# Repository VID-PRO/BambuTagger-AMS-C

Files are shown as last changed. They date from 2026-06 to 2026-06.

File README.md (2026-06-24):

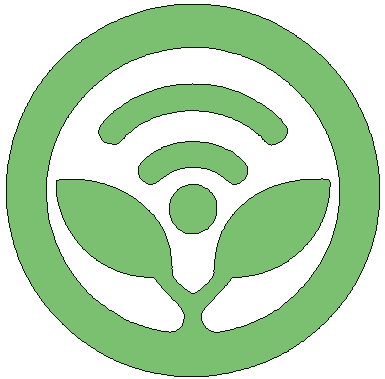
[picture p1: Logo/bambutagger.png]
#  BambuTagger-AMS-C

Multi-spool NFC tag reader for Bambu Lab printers. Reads 4 Bambu Lab filament spool tags via RC522, displays live printer AMS tray data over MQTT, and sends RFID tag data to the printer/BMCU. Fully configurable via web interface with automatic AP fallback and OTA firmware updates.



<p align="center">
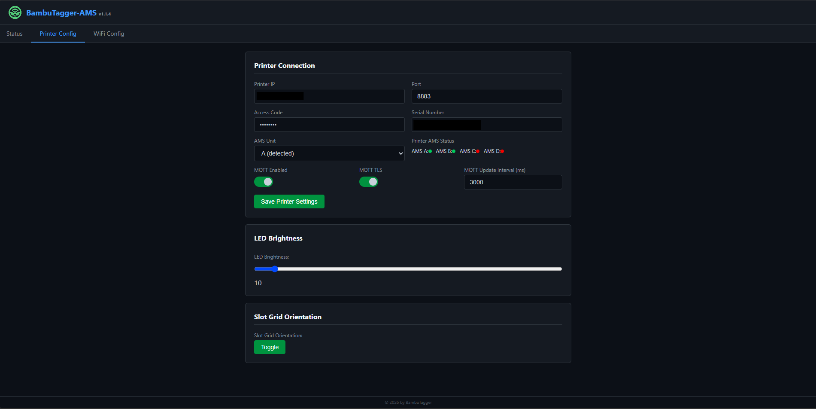
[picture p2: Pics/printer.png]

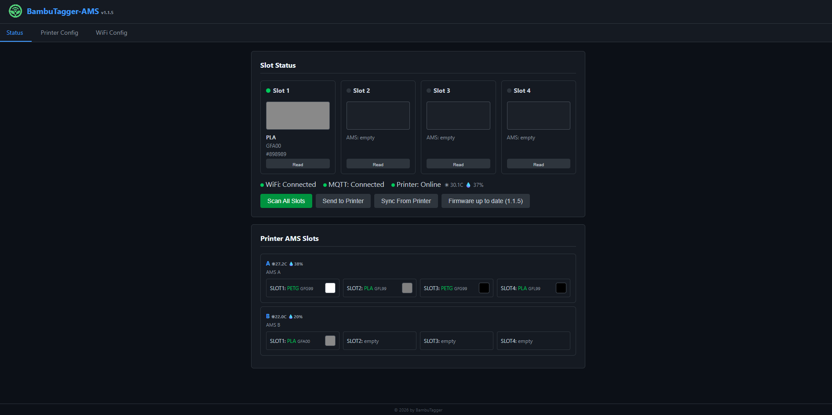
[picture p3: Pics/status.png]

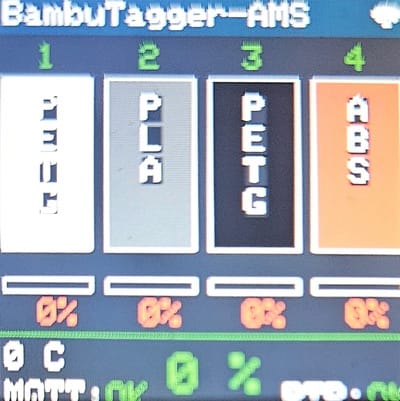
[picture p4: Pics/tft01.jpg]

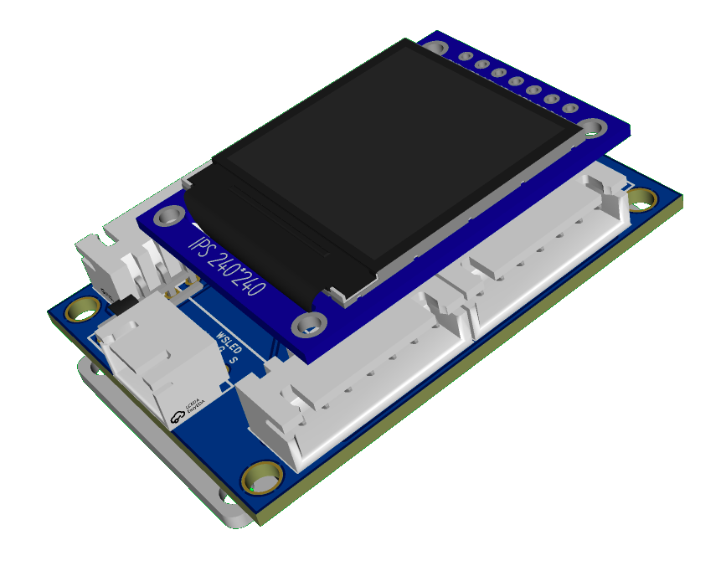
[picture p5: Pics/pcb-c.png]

</p>

---

## Features

| Category | Details |
|---|---|
| **RFID** | 4x RC522 on shared SPI bus; MIFARE Classic 1K (Bambu Lab) + NTAG (SpoolEase/TigerTag/OpenTag3D/OpenSpool) auto-detection |
| **Key derivation** | HKDF-SHA256 with Bambu Lab salt — no hardcoded keys |
| **Tag parsers** | TigerTag v2.1 binary, OpenTag3D MIME binary, OpenSpool JSON, SpoolEase NDEF URI, nested NDEF recursion |
| **Live AMS sync** | Reads tray data (material, color, type) from printer over MQTT |
| **BMCU support** | Sends `ams_filament_setting` with correct `tray_type`, `tray_color`, `nozzle_temp_min/max` |
| **TFT display** | 240×240 1.3" ST7789VW with boot splash, live AMS tray data, OTA progress, BME280 temp/humidity |
| **LEDs** | 4x WS2812 addressable LEDs with per-slot color from printer AMS tray data |
| **Web UI** | 3-tab SPA: Status (merged slots + color swatches), Printer Config, WiFi Config |
| **MQTT bridge** | Subscribes to printer status, publishes `ams_filament_setting` commands |
| **WiFi** | Auto-STA on boot; AP fallback `192.168.4.1` with captive portal |
| **OTA updates** | One-click firmware update from GitHub Releases with TFT progress bar |
| **CI/CD** | GitHub Actions: build on commit, release on version tags |

---

## Hardware

### Bill of Materials

| Component | Notes | Buy |
|---|---|-----
| **ESP32** Dev Module | Base board | https://de.aliexpress.com/item/1005006589341221.html |
| **4x RC522** RFID/NFC readers | SPI interface, shared bus | https://de.aliexpress.com/item/1005006233005745.html |
| **4x WS2812** addressable LEDs | Daisy-chained, single data pin | https://de.aliexpress.com/item/32560280169.html |
| **240×240 1.3" TFT** | ST7789VW SPI display | https://www.aliexpress.com/item/1005007094147766.html |
| **BME280** sensor | Temperature/humidity, I2C | https://de.aliexpress.com/item/1005006824236173.html |
| **PCB** | DIY PCB from JLPCB<br/>only > v1.2 | https://oshwlab.com/bambutagger/project_hdkkdlsn |

### Pin Assignments

**SPI Bus (shared by all RC522 readers)**

| Signal | GPIO |
|---|---|
| MOSI | 23 |
| MISO | 19 |
| SCK | 18 |

**RC522 Readers**

| Reader | SS Pin | RST Pin | Slot | WS2812 Pixel |
|---|---|---|---|---|
| #1 | 13 | 26 | 1 | 0 |
| #2 | 12 | 25 | 2 | 1 |
| #3 | 14 | 33 | 3 | 2 |
| #4 | 27 | 32 | 4 | 3 |

**TFT Display (ST7789VW SPI)**

| Signal | GPIO |
|---|---|
| SDA (MOSI) | 17 |
| SCL (SCK) | 16 |
| DC | 4 |
| RES | 5 |
| BLK (Backlight) | 2 |

**WS2812 LEDs**

| Signal | GPIO |
|---|---|
| Data | 15 |

**BME280**

| Signal | GPIO |
|---|---|
| SCL | 21 |
| SDA | 22 |

---

## Software

### Required Libraries (Arduino Library Manager)

| Library | Version | Notes |
|---|---|---|
| `MFRC522-spi-i2c-uart-async` | latest | Multi-reader SPI sharing (not standard MFRC522) |
| `Adafruit NeoPixel` | ≥ 1.12 | WS2812 LED control |
| `Adafruit GFX Library` | ≥ 1.11 | Graphics primitives |
| `Adafruit ST7735 and ST7789 Library` | ≥ 1.10 | TFT display driver |
| `PubSubClient` | ≥ 2.8 | MQTT client |
| `ArduinoJson` | ≥ 6.x or 7.x | JSON parsing |
| `Adafruit BME280 Library` | latest | Temperature/humidity sensor |
| `mbedTLS` | Built-in | HKDF-SHA256 key derivation |

### Board Settings (Arduino IDE)

| Setting | Value |
|---|---|
| Board | **ESP32 Dev Module** |
| Flash Size | **4 MB** |
| Partition Scheme | **Default 4MB with spiffs** |
| Upload Speed | 921600 |
| Monitor Speed | **115200** |

### Building

1. Install **ESP32 board package** (≥ 3.x):  
   File → Preferences → Additional Board Manager URLs:  
   `https://espressif.github.io/arduino-esp32/package_esp32_index.json`
2. Install libraries listed above via **Tools → Manage Libraries**.
3. Open `BambuTagger-AMS-C.ino`, select **ESP32 Dev Module**, and upload.

---

## WiFi & AP Mode

| Scenario | Behavior |
|---|---|
| No WiFi configured | Opens AP immediately |
| WiFi connection fails | Opens AP after 15 seconds |
| AP active, credentials exist | Retries STA connection every 30 seconds |
| STA connects while AP active | Closes AP, switches to normal mode |

**AP Details:**
- **SSID**: Device name (default: `BambuTagger-AMS`)
- **Security**: Open (no password)
- **IP**: `192.168.4.1`
- **Captive portal**: DNS redirects all domains to the config page

---

## Web Interface

Open a browser to the ESP32's IP (shown on TFT), or `http://192.168.4.1` in AP mode.

| Tab | Description |
|-----|---|
| **Status** | Merged slot status with AMS data + scanned tag data, color swatches, printer AMS cards, OTA button |
| **Printer Config** | Printer IP, Port (8883), Access Code, Serial Number, AMS Unit selector (A/B/C/D), MQTT settings |
| **WiFi Config** | SSID, Password, Device Name |

---

## TFT Display (240×240 1.3" ST7789VW)

```
┌────────────────────────────────────────┐
│ Device Name                      WiFi  │  ← status bar (white bg)
├────────────────────────────────────────┤
│ 1: PLA          [■] #C0C0C0FF   100%   │  ← color swatch + percentage
│ 2: empty                               │
│ 3: empty                               │
│ 4: empty                               │
├────────────────────────────────────────┤
│ 22C        45%                         │  ← BME280 (orange/blue)
│ MQTT:OK                         PTR:OK │  ← status line
└────────────────────────────────────────┘
```

OTA progress shown on TFT with header/footer preserved:  
"OTA Update" → "Downloading..." → "Flashing... 45%" → auto-reboot

---

## Printer Communication

### Subscribe

- **Topic**: `device/<serial>/report`
- **Data**: `push_status` (periodic, ~3KB), `get_version` responses

### Publish

- **Topic**: `device/<serial>/request`

**`ams_filament_setting`** structure:

```json
{
  "print": {
    "sequence_id": "0",
    "command": "ams_filament_setting",
    "ams_id": 0,
    "tray_id": 0,
    "tray_info_idx": "GFA00",
    "tray_color": "RRGGBBFF",
    "nozzle_temp_min": 190,
    "nozzle_temp_max": 230,
    "tray_type": "PLA"
  }
}
```

- `tray_type` derived from filament index prefix (GFA→PLA, GFG→PETG, etc.)
- `tray_color` forced to RRGGBBFF format
- `nozzle_temp_min/max` from tag block 6

---

## Tag Format & Reading

### Supported Tag Types

| Tag Type | Format | Example |
|---|---|---|
| **Bambu Lab** | MIFARE Classic 1K | `Bambu - PLA · C12E1FFF · 1000g/1000g` |
| **SpoolEase** | NTAG, NDEF URI | `SpoolEase - PLA · 000000FF · 1000g/1036g` |
| **TigerTag** | NTAG, binary v2.1 | `TigerTag - ASA-AF · F078B4FF · 1000g/1000g` |
| **OpenSpool** | NTAG, NDEF JSON | `OpenSpool - ASA-AF · F078B4FF · 1000g/1000g` |
| **OpenTag3D** | NTAG, MIME binary | `OpenTag3D - ASA-AF · F078B4FF · 1000g/1000g` |

### Bambu Lab (MIFARE Classic 1K)

| Block | Content |
|---|---|
| 0 | UID (4 bytes) |
| 1 | Variant ID + Material index (e.g. "GFA00") |
| 2 | Filament type short name |
| 4 | Detailed type string (e.g. "PLA Basic") |
| 5 | RGBA color (bytes 0-3) + spool weight LE (bytes 4-5) |
| 6 | Nozzle temps (bytes 8-11 LE) |

### SpoolEase (NTAG, NDEF URI)

URL format: `https://tag.spoolease.io/S1/?TG=...&M=PLA&CC=000000FF&SC=GFL99&WL=1000&WE=179&WF=1215&NN=190&NX=240`

| Param | Field | Description |
|---|---|---|
| `M=` | display type | e.g. "PLA", "PETG" |
| `SC=` | `materialType` | Bambu index for MQTT (e.g. "GFL99") |
| `CC=` | `colorHex` | RGBA hex (e.g. "000000FF") |
| `B=` | `manufacturer` | Brand name (e.g. "Jayo") |
| `WL=` | `remainingGrams` | Remaining filament weight |
| `WE=` | empty spool | Empty spool weight |
| `WF=` | full spool | `totalGrams = WF - WE` |
| `NN=` | `nozzleTempMin` | Min nozzle temp °C |
| `NX=` | `nozzleTempMax` | Max nozzle temp °C |

### TigerTag (NTAG, binary v2.1)

| Offset | Size | Field |
|---|---|---|
| +0 | 4 | ID TigerTag magic (0x5BF59264/0xBC0FCB97/0x6C41A2E1) |
| +4 | 4 | Product ID |
| +8 | 2 | Material ID → lookup table (PLA/PETG/ABS/TPU...) |
| +14 | 2 | Brand ID |
| +16 | 4 | Color 1 RGBA |
| +20 | 3 | Measure (u24 BE) |
| +24 | 2 | Nozzle Temp Min |
| +26 | 2 | Nozzle Temp Max |
| +76 | 3 | Measure Available |

Known material IDs: PLA=38219, PETG=38256, ABS=20562, etc.

### Authentication & Reading

- **Tag auto-detect**: SAK-based type detection (MIFARE 1K vs NTAG)
- **HKDF-SHA256** derives 16 per-sector Key A/B from 4-byte UID
- Bambu KDF salt/info vectors from reverse-engineered firmware
- Falls back to default key `0xFF...FF` for blank sectors
- Failed auth re-wakes tag via antenna power-cycle
- Dead readers auto-skipped (version register 0x92/0x91/0xB2 check)
- SPI: 1 MHz via `MFRC522_SPI`
- NTAG: page-level reads (page+=4, 4 pages per MIFARE_Read)

### Filament Type Mapping

| Prefix | Type |
|---|---|
| GFA-GFE, GFL | PLA |
| GFG | PETG |
| GFH, GFI | ABS |
| GFJ | ASA |
| GFK | TPU |

---

## OTA Updates

- **Button**: "Update Firmware" on Status page (shows "Update to vX.Y.Z" or "up to date")
- **Overlay**: full-screen progress overlay with spinner, status text, progress bar
- **Endpoint**: `POST /api/ota` triggers update, `GET /api/ota-check` checks for newer version
- Downloads latest `.ino.bin` from GitHub Releases, flashes via `Update.h`
- 3 retry attempts with 5s stall detection, fresh HTTP client per attempt
- TFT shows "Checking version..." → "Downloading..." → "Flashing..." with percentage
- Device auto-reboots after successful flash, web UI auto-reloads

---

## CI / CD

Workflow at `GHActions/release.yml`:

- **On push/PR**: compiles sketch, uploads artifacts
- **On release tag**: creates merged flash binary + OTA binary, attaches to GitHub Release
- Arduino cache for fast rebuilds, pinned esp32:esp32@3.0.7 core

---

## Configuration Defaults

| Setting | Default |
|---|---|
| WiFi SSID | (empty) |
| WiFi Password | (empty) |
| Device Name | BambuTagger-AMS |
| Printer IP | 192.168.1.100 |
| Printer Port | 8883 |
| Access Code | (empty) |
| Printer Serial | (empty) |
| AMS Unit | A (0) |
| MQTT Enabled | Yes |
| MQTT TLS | No |
| MQTT Update Interval | 3000 ms |
| RFID Poll Interval | 100 ms |
| Firmware Version | 1.0.8 |

---

## Credits & References

- [RFID-Tag-Guide](https://github.com/Bambu-Research-Group/RFID-Tag-Guide)
- Display library: [Adafruit ST7735/ST7789](https://github.com/adafruit/Adafruit-ST7735-Library)
- RFID library: [MFRC522-spi-i2c-uart-async](https://github.com/miguelbalboa/rfid)
- OpenTag3D spec: [opentag3d.info](https://opentag3d.info)

---

## License

This project is provided as-is for personal and educational use.  
Bambu Lab trademarks and spool tag data formats are the property of Bambu Lab.

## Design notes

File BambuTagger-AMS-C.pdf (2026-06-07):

# BambuTagger-AMS-C

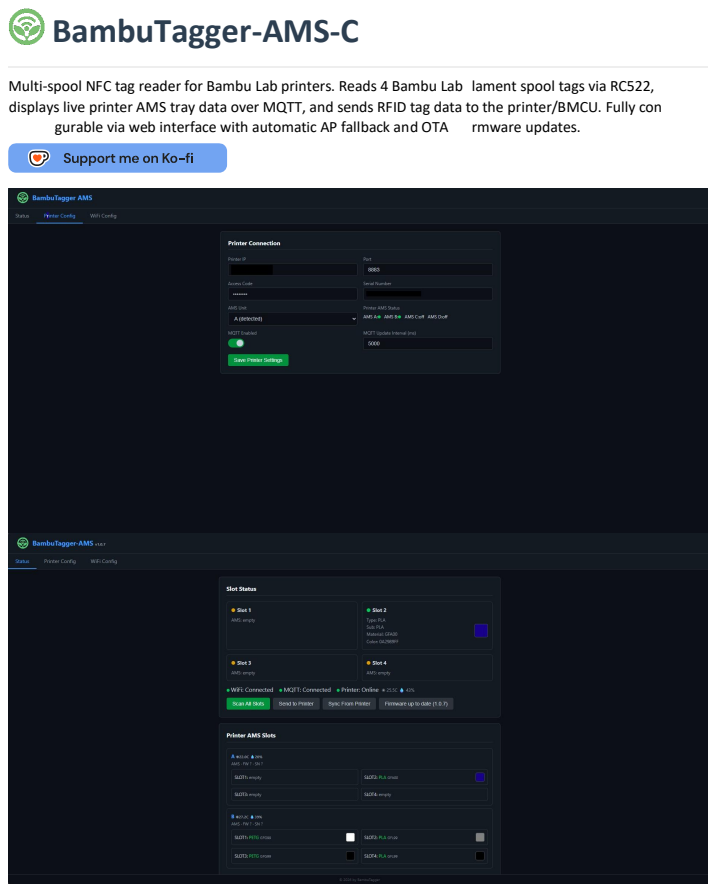
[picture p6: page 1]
gurable via web interface with automatic AP fallback and OTA; rmware updates.

Multi-spool NFC tag reader for Bambu Lab printers. Reads 4 Bambu Lab lament spool tags via RC522,
displays live printer AMS tray data over MQTT, and sends RFID tag data to the printer/BMCU. Fully con

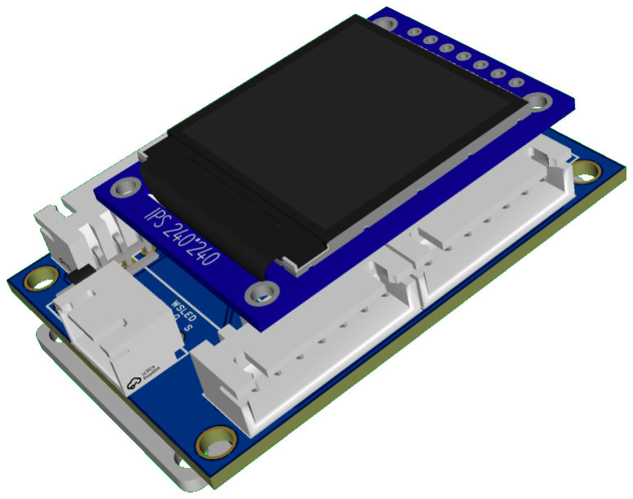
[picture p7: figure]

# Features

Category | Details
RFID | 4x RC522 on shared SPI bus; MIFARE Classic 1K (Bambu Lab) + NTAG (SpoolEase/TigerTag/OpenTag3D/OpenSpool) auto-detection
Key derivation | HKDF-SHA256 with Bambu Lab salt — no hardcoded keys
Tag parsers | TigerTag v2.1 binary, OpenTag3D MIME binary, OpenSpool JSON, SpoolEase NDEF URI, nested NDEF recursion
Live AMS sync | Reads tray data (material, color, type) from printer over MQTT
BMCU support | Sends ams_filament_setting with correct tray_type , tray_color , nozzle_temp_min/max
TFT display | 240×240 1.3" ST7789VW with boot splash, live AMS tray data, OTA progress, BME280 temp/humidity
Category | Details

LEDs | 4x WS2812 addressable LEDs with per-slot color from printer AMS tray data
Web UI | 3-tab SPA: Status (merged slots + color swatches), Printer Con g, WiFi Con g
MQTT bridge | Subscribes to printer status, publishes ams_filament_setting commands
WiFi | Auto-STA on boot; AP fallback 192.168.4.1 with captive portal
OTA updates | One-click rmware update from GitHub Releases with TFT progress bar
CI/CD | GitHub Actions: build on commit, release on version tags

# Hardware

## Bill of Materials

Component | Notes | Buy
ESP32 Dev Module | Base board | https://de.aliexpress.com/item/1005006589341221.html
4x RC522 RFID/NFC readers | SPI interface, shared bus | https://de.aliexpress.com/item/1005006233005745.html
4x WS2812 addressable LEDs | Daisy-chained, single data pin | https://de.aliexpress.com/item/32560280169.html
240×240 1.3" TFT | ST7789VW SPI display | https://www.aliexpress.com/item/1005007094147766.html
BME280 sensor | Temperature/humidity, I2C | https://de.aliexpress.com/item/1005006824236173.html
PCB | DIY PCB from JLPCB | https://oshwlab.com/bambutagger/project_hdkkdlsn

## Pin Assignments

SPI Bus (shared by all RC522 readers)

Signal | GPIO
MOSI | 23
Signal | GPIO
MISO | 19
SCK | 18

RC522 Readers

Reader | SS Pin | RST Pin | Slot | WS2812 Pixel
#1 | 13 | 26 | 1 | 0

#2 | 12 | 25 | 2 | 1

#3 | 14 | 33 | 3 | 2

#4 | 27 | 32 | 4 | 3

TFT Display (ST7789VW SPI)

Signal | GPIO
SDA (MOSI) | 17
SCL (SCK) | 16
DC | 4
RES | 5
BLK (Backlight) | 2

WS2812 LEDs

Signal | GPIO
Data | 15

# Software

## Required Libraries (Arduino Library Manager)

Library | Version | Notes
MFRC522-spi-i2c-uart-async | latest | Multi-reader SPI sharing (not standard MFRC522)
Adafruit NeoPixel | ≥ 1.12 | WS2812 LED control
Library | Version | Notes
Adafruit GFX Library | ≥ 1.11 | Graphics primitives
Adafruit ST7735 and ST7789 Library | ≥ 1.10 | TFT display driver
PubSubClient | ≥ 2.8 | MQTT client
ArduinoJson | ≥ 6.x or 7.x | JSON parsing

## Board Settings (Arduino IDE)

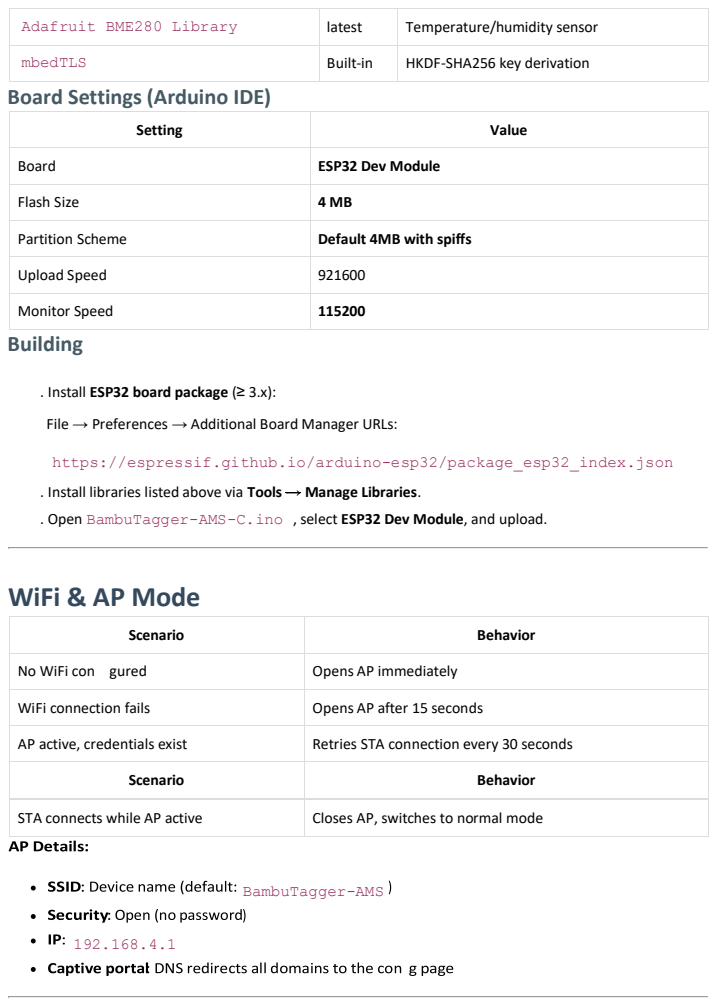
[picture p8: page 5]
Building; BambuTagger-AMS

Adafruit BME280 Library | latest | Temperature/humidity sensor

mbedTLS | Built-in | HKDF-SHA256 key derivation

Setting | Value

Board | ESP32 Dev Module

Flash Size | 4 MB

Partition Scheme | Default 4MB with spiffs

Upload Speed | 921600

Monitor Speed | 115200

. Install ESP32 board package (≥ 3.x):

File → Preferences → Additional Board Manager URLs:

https://espressif.github.io/arduino-esp32/package_esp32_index.json
. Install libraries listed above via Tools → Manage Libraries.
. Open BambuTagger-AMS-C.ino , select ESP32 Dev Module, and upload.

WiFi & AP Mode

Scenario | Behavior

No WiFi con gured | Opens AP immediately

WiFi connection fails | Opens AP after 15 seconds

AP active, credentials exist | Retries STA connection every 30 seconds

STA connects while AP active | Closes AP, switches to normal mode

# Web Interface

Open a browser to the ESP32's IP (shown on TFT), or http://192.168.4.1 in AP mode.

Tab | Description
Status | Merged slot status with AMS data + scanned tag data, color swatches, printer AMS cards, OTA button
Printer Con g | Printer IP, Port (8883), Access Code, Serial Number, AMS Unit selector (A/B/C/D), MQTT settings
WiFi Con g | SSID, Password, Device Name

# TFT Display (240×240 1.3" ST7789VW)

┌────────────────────────────────────────┐

│ Device Name | | WiFi | │ ← status bar (white bg)

├────────────────────────────────────────┤

│ 1: PLA | [■] #C0C0C0FF | 100% | │ ← color swatch + percentage
│ 2: empty | | | │
│ 3: empty | | | │
│ 4: empty | | | │

├────────────────────────────────────────┤

│ 22C | 45% | │ ← BME280 (orange/blue)
│ MQTT:OK | PTR:OK │ ← status line

└────────────────────────────────────────┘

OTA progress shown on TFT with header/footer preserved:

"OTA Update" → "Downloading..." → "Flashing... 45%" → auto-reboot

# Printer Communication

## Subscribe

Topic: device/<serial>/report

Data: push_status (periodic, ~3KB), get_version responses

## Publish

Topic: device/<serial>/request

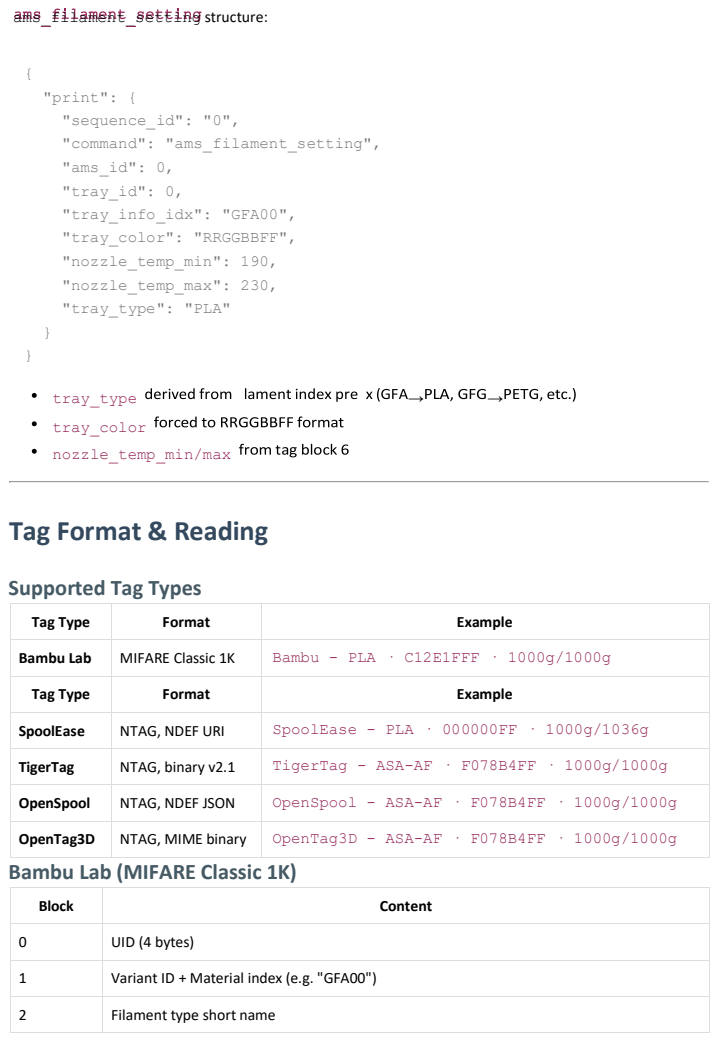
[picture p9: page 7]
ams_filament_setting structure:; "print": {; "sequence_id": "0",; "command": "ams_filament_setting",; "ams_id": 0,; "tray_id": 0,; "tray_info_idx": "GFA00",; "tray_color": "RRGGBBFF",; "nozzle_temp_min": 190,; "nozzle_temp_max": 230,; "tray_type": "PLA"; tray_type; tray_color; nozzle_temp_min/max

Tag Format & Reading

Supported Tag Types

Tag Type | Format | Example

Bambu Lab | MIFARE Classic 1K | Bambu - PLA · C12E1FFF · 1000g/1000g

SpoolEase | NTAG, NDEF URI | SpoolEase - PLA · 000000FF · 1000g/1036g

TigerTag | NTAG, binary v2.1 | TigerTag - ASA-AF · F078B4FF · 1000g/1000g

OpenSpool | NTAG, NDEF JSON | OpenSpool - ASA-AF · F078B4FF · 1000g/1000g

OpenTag3D | NTAG, MIME binary | OpenTag3D - ASA-AF · F078B4FF · 1000g/1000g

Bambu Lab (MIFARE Classic 1K)

Block | Content

0 | UID (4 bytes)

1 | Variant ID + Material index (e.g. "GFA00")

2 | Filament type short name

4 | Detailed type string (e.g. "PLA Basic")
5 | RGBA color (bytes 0-3) + spool weight LE (bytes 4-5)
6 | Nozzle temps (bytes 8-11 LE)

## SpoolEase (NTAG, NDEF URI)

URL format: https://tag.spoolease.io/S1/?

TG=...&M=PLA&CC=000000FF&SC=GFL99&WL=1000&WE=179&WF=1215&NN=190&NX=240

Param | Field | Description
M= | display type | e.g. "PLA", "PETG"
SC= | materialType | Bambu index for MQTT (e.g. "GFL99")
CC= | colorHex | RGBA hex (e.g. "000000FF")
B= | manufacturer | Brand name (e.g. "Jayo")
WL= | remainingGrams | Remaining lament weight
WE= | empty spool | Empty spool weight
WF= | full spool | totalGrams = WF - WE
NN= | nozzleTempMin | Min nozzle temp °C
NX= | nozzleTempMax | Max nozzle temp °C

## TigerTag (NTAG, binary v2.1)

Offset | Size | Field
+0 | 4 | ID TigerTag magic (0x5BF59264/0xBC0FCB97/0x6C41A2E1)
+4 | 4 | Product ID
+8 | 2 | Material ID → lookup table (PLA/PETG/ABS/TPU...)
+14 | 2 | Brand ID
+16 | 4 | Color 1 RGBA
+20 | 3 | Measure (u24 BE)
+24 | 2 | Nozzle Temp Min
+26 | 2 | Nozzle Temp Max
+76 | 3 | Measure Available

Known material IDs: PLA=38219, PETG=38256, ABS=20562, etc.

## Authentication & Reading

Tag auto-detect: SAK-based type detection (MIFARE 1K vs NTAG) HKDF-SHA256 derives 16 per-sector Key A/B from 4-byte UID Bambu KDF salt/info vectors from reverse-engineered rmware

Falls back to default key 0xFF...FF for blank sectors
Failed auth re-wakes tag via antenna power-cycle
Dead readers auto-skipped (version register 0x92/0x91/0xB2 check)

SPI: 1 MHz via MFRC522_SPI

NTAG: page-level reads (page+=4, 4 pages per MIFARE_Read)

## Filament Type Mapping

Pre x | Type
GFA-GFE, GFL | PLA
GFG | PETG
GFH, GFI | ABS
GFJ | ASA
GFK | TPU

# OTA Updates

Button: "Update Firmware" on Status page (shows "Update to vX.Y.Z" or "up to date")
Overlay: full-screen progress overlay with spinner, status text, progress bar
Endpoint: POST /api/ota triggers update, GET /api/ota-check checks for newer version

Downloads latest .ino.bin from GitHub Releases, ashes via Update.h

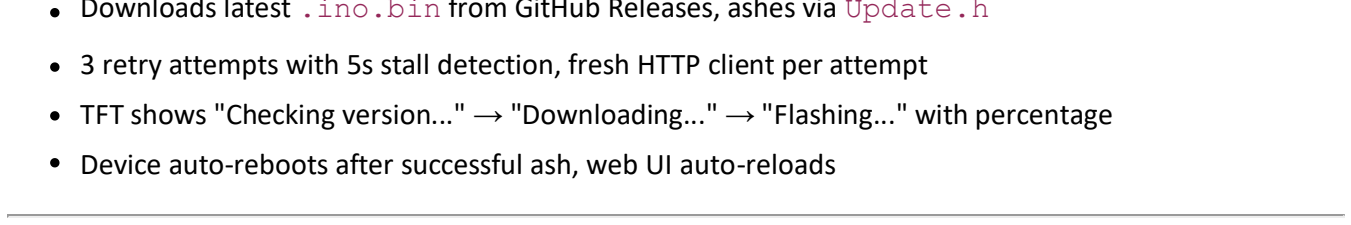
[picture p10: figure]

3 retry attempts with 5s stall detection, fresh HTTP client per attempt
TFT shows "Checking version..." → "Downloading..." → "Flashing..." with percentage Device auto-reboots after successful ash, web UI auto-reloads

# CI / CD

Work ow at GHActions/release.yml :

On push/PR: compiles sketch, uploads artifacts

On release tag: creates merged ash binary + OTA binary, attaches to GitHub Release Arduino cache for fast rebuilds, pinned esp32:esp32@3.0.7 core

# Con guration Defaults

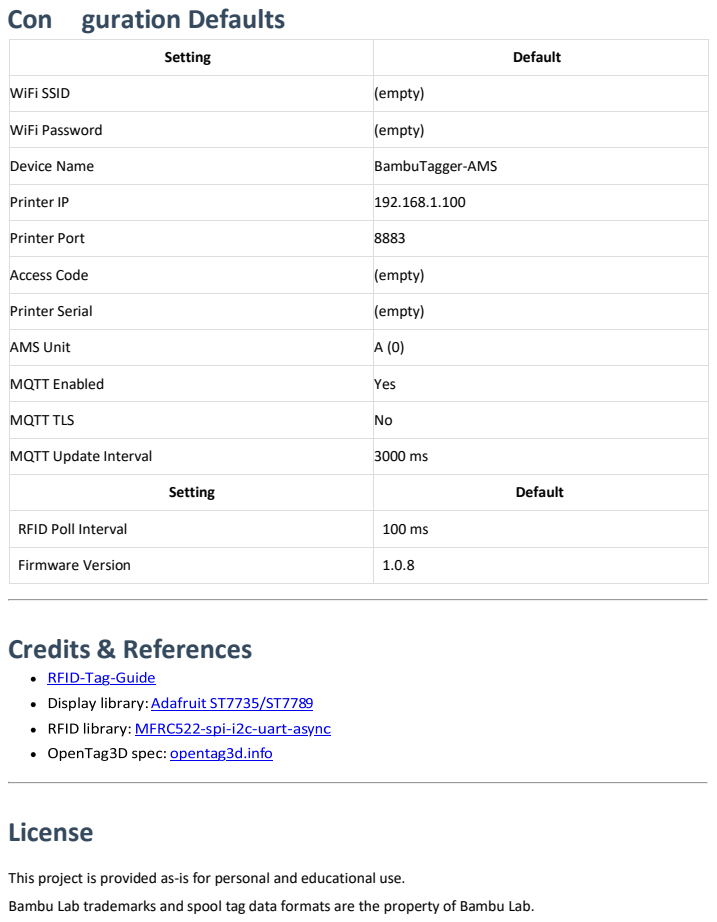
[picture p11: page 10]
Credits & References; License

Setting | Default

WiFi SSID | (empty)

WiFi Password | (empty)

Device Name | BambuTagger-AMS

Printer IP | 192.168.1.100

Printer Port | 8883

Access Code | (empty)

Printer Serial | (empty)

AMS Unit | A (0)

MQTT Enabled | Yes

MQTT TLS | No

MQTT Update Interval | 3000 ms

RFID Poll Interval | 100 ms

Firmware Version | 1.0.8

This project is provided as-is for personal and educational use.
Bambu Lab trademarks and spool tag data formats are the property of Bambu Lab.

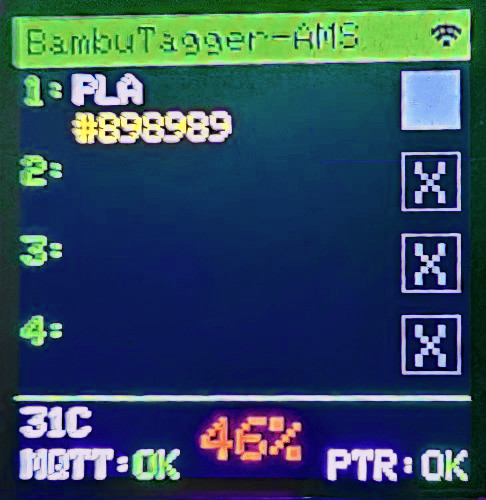
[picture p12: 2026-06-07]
Pics/tft02.jpg

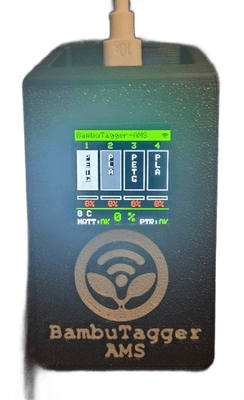
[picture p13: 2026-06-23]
Pics/BT-AMS-case.png

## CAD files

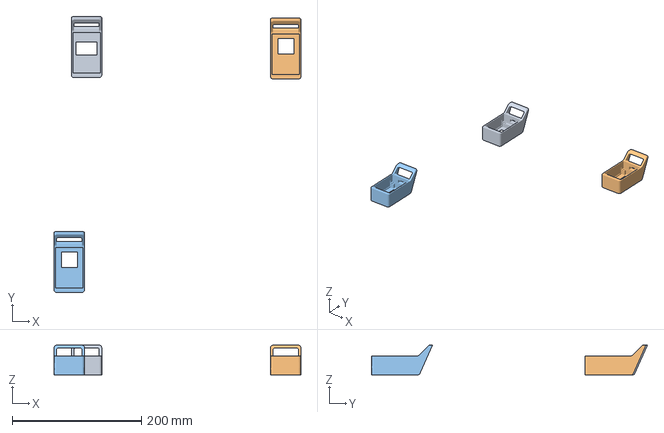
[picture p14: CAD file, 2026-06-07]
3DPrints/BambuTagger-AMS.3mf
381.9 x 427.1 x 46.1 mm
BambuTagger-AMS
BambuTagger-AMS-C x 2

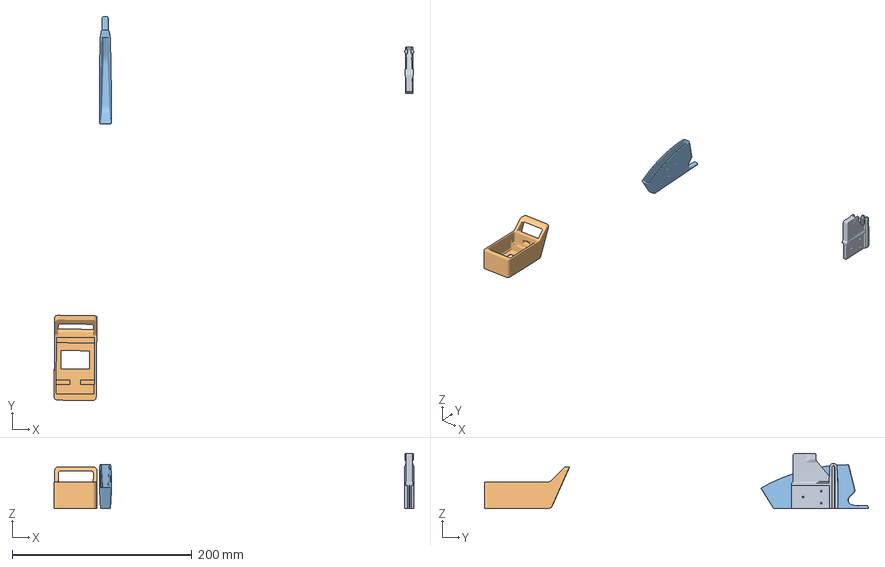
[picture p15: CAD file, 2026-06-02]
3DPrints/BambuTagger-AMS-AMS.3mf
400.6 x 427.3 x 61.2 mm
BambuTagger-AMS (2).stl
BambuTagger-AMS.stl
BambuTagger-AMS (1).stl

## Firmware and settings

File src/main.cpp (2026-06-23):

/*
 * BambuTagger AMS - Multi-Spool NFC Tag Reader for Bambu Lab
 *
 * Arduino IDE: ESP32 Dev Module (Tools > Board > ESP32 > ESP32 Dev Module)
 *
 * Required libraries (install via Tools > Manage Libraries):
 *   - MFRC522-spi-i2c-uart-async
 *   - Adafruit NeoPixel by Adafruit    (v1.12.3+)
 *   - Adafruit GFX Library by Adafruit (v1.11.11+)
 *   - Adafruit ST7735 and ST7789 Library by Adafruit (v1.10.0+)
 *   - PubSubClient   by Nick O'Leary   (v2.8+)
 *   - ArduinoJson    by Benoit Blanchon (v6.21.5+)
 *
 * Wiring: see config.h for pin assignments
 */

#include <ESPmDNS.h>
#include <WiFi.h>
#include <DNSServer.h>
#include <HTTPClient.h>
#include <Update.h>
#include <Adafruit_BME280.h>
#include <HTTPUpdate.h>

#include <esp_http_client.h>
#include <esp_ota_ops.h>

#include "config.h"
#include "rfid_manager.h"
#include "led_manager.h"
#include "display_manager.h"
#include "web_server.h"
#include "bambu_printer.h"

SystemConfig cfg;
RfidManager rfidManager;
LedManager ledManager;
DisplayManager displayManager;
WebInterface webInterface;
BambuPrinter bambuPrinter;
DNSServer dnsServer;
Adafruit_BME280 bme;
float bmeTemp = 0;
float bmeHumidity = 0;
bool bmeOk = false;

bool wifiConnected = false;
bool apMode = false;
String localIP = "";
const byte DNS_PORT = 53;

void handleReboot();
void performOTAUpdate();
void connectWiFi();
void startCaptivePortal();
void updateLedStatus();

SET_LOOP_TASK_STACK_SIZE(16 * 1024);

void setup() {
  Serial.begin(115200);
  delay(1500);
  Serial.println();
  Serial.print(F("=== BambuTagger AMS v"));
  Serial.print(FIRMWARE_VERSION);
  Serial.println(F(" ==="));
  Serial.println(F("Multi-Spool NFC Tag Reader for Bambu Lab"));

  loadConfig(cfg);

  displayManager.begin(cfg.deviceName);
  Serial.println(F("TFT initialized"));
  displayManager.showBootScreen();
  displayManager.setLayout(cfg.layoutVertical);
  delay(2000);

  Wire.begin();
  bmeOk = bme.begin(0x76);
  if (!bmeOk) bmeOk = bme.begin(0x77);
  if (bmeOk) {
    Serial.println(F("BME280 sensor found"));
  } else {
    Serial.println(F("BME280 not found"));
  }

  Serial.print(F("Device: "));
  Serial.println(cfg.deviceName);


  ledManager.begin();
  Preferences prefs;
  prefs.begin("led", false);
  uint8_t savedBrightness = prefs.getUChar("brightness", LED_BRIGHTNESS);
  prefs.end();

  ledManager.setBrightness(savedBrightness);

  ledManager.setAllLeds(LED_IDLE);
  ledManager.update();

  rfidManager.begin();
  Serial.println(F("RFID readers initialized"));

  connectWiFi();

  if (wifiConnected) {
    bambuPrinter.begin(cfg);
  }

  webInterface.begin(cfg, &rfidManager, &bambuPrinter, handleReboot, performOTAUpdate);
  webInterface.updateStatus(wifiConnected, localIP.c_str(), false, false);
  if (wifiConnected) {
    Serial.println(F("Web server started on port 80"));
    Serial.println(localIP);
  } else {
    Serial.println(F("Web server started on AP 192.168.4.1"));
  }

  ledManager.setAllLeds(wifiConnected ? LED_WIFI_CONNECTED : LED_WIFI_DISCONNECTED);
  ledManager.update();

  Serial.println(F("Setup complete"));
}

void loop() {
  rfidManager.loop();
  webInterface.handleClient();
  yield();
  if (apMode) {
    dnsServer.processNextRequest();
  }
  if (wifiConnected) {
    static unsigned long lastMqttLoop = 0;
    if (millis() - lastMqttLoop > 200) {
      lastMqttLoop = millis();
      bambuPrinter.update();
    }
  }

  static unsigned long lastReconnectCheck = 0;
  static unsigned long lastLedUpdate = 0;
  static unsigned long lastDisplayUpdate = 0;
  static unsigned long lastMqttUpdate = 0;
  unsigned long now = millis();

  if (apMode && strlen(cfg.wifiSSID) > 0 && now - lastReconnectCheck > 30000) {
    lastReconnectCheck = now;
    Serial.println(F("AP Mode: retrying STA connection..."));
    WiFi.begin(cfg.wifiSSID, cfg.wifiPassword);
  }

  if (WiFi.status() == WL_CONNECTED && apMode) {
    apMode = false;
    wifiConnected = true;
    localIP = WiFi.localIP().toString();
    dnsServer.stop();
    Serial.print(F("WiFi connected! IP: "));
    Serial.println(localIP);
    displayManager.showOtaProgress("WiFi Connected", localIP.c_str());
    bambuPrinter.begin(cfg);
    if (MDNS.begin(cfg.deviceName)) {
      Serial.println(F("mDNS responder started"));
    }
  }

  static unsigned long lastBmeRead = 0;
  if (bmeOk && now - lastBmeRead > 5000) {
    lastBmeRead = now;
    bmeTemp = bme.readTemperature();
    bmeHumidity = bme.readHumidity();
  }

  static unsigned long lastBmeSend = 0;
  if (bmeOk && now - lastBmeSend > 60000) {
    lastBmeSend = now;
    bambuPrinter.sendBmeData(bmeTemp, bmeHumidity);
  }

  if (now - lastLedUpdate > 200) {
    lastLedUpdate = now;
    updateLedStatus();
    ledManager.update();
  }

  if (now - lastDisplayUpdate > 2000) {
    lastDisplayUpdate = now;
    SpoolInfo displaySlots[NUM_SLOTS];
    for (uint8_t i = 0; i < NUM_SLOTS; i++) {
      rfidManager.getSpoolInfo(i, displaySlots[i]);
    }
    bool mqttOk = bambuPrinter.isConnected();
    webInterface.updateStatus(wifiConnected, localIP.c_str(), mqttOk,
                              (bambuPrinter.getState() == PRINTER_CONNECTED));
    displayManager.update(displaySlots, wifiConnected, mqttOk,
                          &bambuPrinter, cfg.amsUnit, bmeTemp, bmeHumidity);
  }

  if (now - lastMqttUpdate > (cfg.mqttUpdateIntervalMs > 0 ? cfg.mqttUpdateIntervalMs : 5000)) {
    lastMqttUpdate = now;
    if (wifiConnected) {
      bool mqttOk = bambuPrinter.isConnected();
      webInterface.updateStatus(wifiConnected, localIP.c_str(), mqttOk,
                                (bambuPrinter.getState() == PRINTER_CONNECTED));

      if (cfg.mqttEnabled && mqttOk) {
        for (uint8_t i = 0; i < NUM_SLOTS; i++) {
          SpoolInfo info;
          if (rfidManager.getSpoolInfo(i, info) && info.present && info.tagReadSuccess) {
            bambuPrinter.sendSpoolData(i, info);
          }
        }
      }
    }
  }
}

void connectWiFi() {
  if (strlen(cfg.wifiSSID) == 0) {
    Serial.println(F("No WiFi credentials configured — starting AP"));
    wifiConnected = false;
    startCaptivePortal();
    return;
  }

  Serial.print(F("Connecting to WiFi: "));
  Serial.println(cfg.wifiSSID);

  WiFi.setHostname(cfg.deviceName);
  WiFi.mode(WIFI_STA);
  WiFi.begin(cfg.wifiSSID, cfg.wifiPassword);

  ledManager.setAllLeds(LED_WIFI_DISCONNECTED);
  ledManager.update();

  int attempts = 0;
  while (WiFi.status() != WL_CONNECTED && attempts < 30) {
    delay(500);
    Serial.print(".");
    attempts++;
  }
  Serial.println();

  if (WiFi.status() == WL_CONNECTED) {
    wifiConnected = true;
    apMode = false;
    localIP = WiFi.localIP().toString();
    Serial.print(F("Connected! IP: "));
    Serial.println(localIP);
    displayManager.showOtaProgress("WiFi Connected", localIP.c_str());

    if (MDNS.begin(cfg.deviceName)) {
      Serial.println(F("mDNS responder started"));
    }
  } else {
    wifiConnected = false;
    Serial.println(F("WiFi connection failed — starting AP"));
    displayManager.showOtaProgress("WiFi Failed!", "Opening AP mode...");
    startCaptivePortal();
  }
}

void startCaptivePortal() {
  apMode = true;
  WiFi.mode(WIFI_AP);
  WiFi.softAP(cfg.deviceName, NULL);
  delay(100);

  IPAddress apIP(192, 168, 4, 1);
  WiFi.softAPConfig(apIP, apIP, IPAddress(255, 255, 255, 0));
  localIP = "192.168.4.1";

  dnsServer.start(DNS_PORT, "*", apIP);

  Serial.print(F("AP started: "));
  Serial.print(cfg.deviceName);
  Serial.println(F(" (open)"));
  Serial.println(F("Connect and visit http://192.168.4.1"));

  char apMsg1[32];
  char apMsg2[32];
  char apMsg3[32];
  snprintf(apMsg1, sizeof(apMsg1), "WiFi: %s", cfg.deviceName);
  snprintf(apMsg2, sizeof(apMsg2), "IP: 192.168.4.1");
  snprintf(apMsg3, sizeof(apMsg3), "Configure WiFi");
  displayManager.showOtaProgress(apMsg1, apMsg2, apMsg3);
}

static uint8_t hexToByte(const char* hex) {
  uint8_t val = 0;
  for (uint8_t i = 0; i < 2; i++) {
    char c = hex[i];
    val <<= 4;
    if (c >= '0' && c <= '9') val |= (c - '0');
    else if (c >= 'A' && c <= 'F') val |= (c - 'A' + 10);
    else if (c >= 'a' && c <= 'f') val |= (c - 'a' + 10);
  }
  return val;
}

void updateLedStatus() {
  uint8_t amsUnit = cfg.amsUnit;
  for (uint8_t i = 0; i < NUM_SLOTS; i++) {
    if (!wifiConnected && !apMode) {
      ledManager.setSlotLed(i, LED_WIFI_DISCONNECTED);
    } else if (apMode) {
      ledManager.setSlotLed(i, LED_IDLE);
    } else if (bambuPrinter.isAmsDetected(amsUnit)) {
      const char* col = bambuPrinter.getAmsTrayColor(amsUnit, i);
      if (col && col[0]) {
        uint8_t r = hexToByte(col);
        uint8_t g = hexToByte(col + 2);
        uint8_t b = hexToByte(col + 4);
        ledManager.setSlotColor(i, r, g, b);
      } else {
        ledManager.setSlotLed(i, LED_IDLE);
      }
    } else {
      ledManager.setSlotLed(i, LED_IDLE);
    }
  }
}

void handleReboot() {
  Serial.println(F("Reboot requested via web..."));
  delay(500);
  ESP.restart();
}

void performOTAUpdate() {
  static bool otaRunning = false;
  if (otaRunning) return;
  otaRunning = true;
  displayManager.showOtaProgress("OTA Update", "Checking version...");

  String dlUrl;
  int binSize = 0;
  String tag;

  {
    // Get latest tag via redirect — no API, no rate limits, no JSON
    WiFiClientSecure client;  // ← add this
    HTTPClient http;          // ← add this
    client.setInsecure();
    client.setTimeout(10000);
    http.setFollowRedirects(HTTPC_DISABLE_FOLLOW_REDIRECTS);
    http.begin(client, String("https://github.com/") + OTA_REPO + "/releases/latest");
    http.addHeader("User-Agent", String("BambuTagger-AMS/") + FIRMWARE_VERSION);
    const char* hdrs[] = { "Location" };
    http.collectHeaders(hdrs, 1);

    int code = http.GET();
    String latest = "";
    if ((code == 301 || code == 302) && http.hasHeader("Location")) {
      String loc = http.header("Location");
      int tagIdx = loc.lastIndexOf("/tag/");
      if (tagIdx >= 0) latest = loc.substring(tagIdx + 5);
    }
    http.end();

    if (latest.isEmpty()) {
      displayManager.showOtaProgress("OTA Update", "", "No release found");
      otaRunning = false;
      delay(3000);
      return;
    }

    // Version check
    tag = latest;
    const char* r = latest.c_str();
    if (r[0] == 'v' || r[0] == 'V') r++;
    const char* l = FIRMWARE_VERSION;
    if (l[0] == 'v' || l[0] == 'V') l++;
    int rMaj = 0, rMin = 0, rPat = 0, lMaj = 0, lMin = 0, lPat = 0;
    sscanf(r, "%d.%d.%d", &rMaj, &rMin, &rPat);
    sscanf(l, "%d.%d.%d", &lMaj, &lMin, &lPat);
    if (rMaj * 10000 + rMin * 100 + rPat <= lMaj * 10000 + lMin * 100 + lPat) {
      displayManager.showOtaProgress("OTA Update", "", "Already up to date");
      otaRunning = false;
      delay(3000);
      return;
    }

    // Construct download URL directly — no asset JSON needed
    dlUrl = String("https://github.com/") + OTA_REPO
            + "/releases/download/" + latest
            + "/firmware.bin";
    Serial.printf("[OTA] tag: %s\n", latest.c_str());
    Serial.printf("[OTA] dlUrl: %s\n", dlUrl.c_str());
  }  // ← client, http destroyed here — heap reclaimed

  if (!dlUrl.length()) {
    displayManager.showOtaProgress("OTA Update", "", "No .bin found");
    otaRunning = false;
    delay(3000);
    return;
  }

  displayManager.showOtaProgress("OTA Update", "Downloading...", tag.c_str());

  String finalUrl = dlUrl;
  {
    WiFiClientSecure rc;
    rc.setInsecure();
    rc.setTimeout(10000);
    HTTPClient rh;
    const char* hdrs[] = { "Location" };
    rh.collectHeaders(hdrs, 1);
    rh.begin(rc, dlUrl);
    rh.addHeader("User-Agent", String("BambuTagger-AMS/") + FIRMWARE_VERSION);
    rh.setFollowRedirects(HTTPC_DISABLE_FOLLOW_REDIRECTS);
    int code = rh.GET();
    Serial.printf("[OTA] redirect code: %d\n", code);
    if ((code == 301 || code == 302) && rh.hasHeader("Location")) {
      finalUrl = rh.header("Location");
      Serial.printf("[OTA] CDN URL: %s\n", finalUrl.c_str());
    }
    rh.end();
  }

    // Raw WiFiClientSecure — same as redirect blocks, bypasses IDF TLS enforcement
  String dlHost, dlPath;
  {
    String u = finalUrl;
    if (u.startsWith("https://")) u = u.substring(8);
    int si = u.indexOf('/');
    dlHost = (si >= 0) ? u.substring(0, si) : u;
    dlPath = (si >= 0) ? u.substring(si) : "/";
  }

  WiFiClientSecure dlClient;
  dlClient.setInsecure();
  dlClient.setTimeout(30000);

  displayManager.showOtaProgress("OTA Update", tag.c_str(), "Connecting...");
  if (!dlClient.connect(dlHost.c_str(), 443)) {
    Serial.println("[OTA] CDN connect failed");
    displayManager.showOtaProgress("OTA Update", "", "Connect failed");
    otaRunning = false; delay(3000); return;
  }

  // Send raw HTTP/1.1 GET
  dlClient.print(String("GET ") + dlPath + " HTTP/1.1\r\n");
  dlClient.print(String("Host: ") + dlHost + "\r\n");
  dlClient.print("User-Agent: BambuTagger-AMS/" FIRMWARE_VERSION "\r\n");
  dlClient.print("Connection: close\r\n\r\n");

  // Parse response headers
  int httpStatus = 0, contentLen = -1;
  {
    String line = dlClient.readStringUntil('\n');
    line.trim();
    if (line.length() > 9) httpStatus = line.substring(9, 12).toInt();
    Serial.printf("[OTA] HTTP status: %d\n", httpStatus);
    while (true) {
      line = dlClient.readStringUntil('\n');
      line.trim();
      if (line.isEmpty()) break;
      String lower = line; lower.toLowerCase();
      if (lower.startsWith("content-length:")) {
        String val = line.substring(15);
        val.trim();
        contentLen = val.toInt();
      }
    }
    Serial.printf("[OTA] Content-Length: %d\n", contentLen);
  }

  if (httpStatus != 200 || contentLen <= 0) {
    dlClient.stop();
    displayManager.showOtaProgress("OTA Update", "", "Bad response");
    otaRunning = false; delay(3000); return;
  }

  const esp_partition_t *part = esp_ota_get_next_update_partition(NULL);
  esp_ota_handle_t otaHandle = 0;
  if (esp_ota_begin(part, contentLen, &otaHandle) != ESP_OK) {
    dlClient.stop();
    displayManager.showOtaProgress("OTA Update", "", "OTA begin failed");
    otaRunning = false; delay(3000); return;
  }

  uint8_t buf[2048];
  int written = 0, lastPct = -1;
  unsigned long lastData = millis();

  while (written < contentLen) {
    int avail = dlClient.available();
    if (avail > 0) {
      lastData = millis();
      int rd = dlClient.read(buf, min(avail, (int)sizeof(buf)));
      if (rd > 0) {
        esp_ota_write(otaHandle, buf, rd);
        written += rd;
        int pct = (written * 100) / contentLen;
        if (pct != lastPct) {
          Serial.printf("[OTA] progress: %d / %d\n", written, contentLen);
          displayManager.showOtaProgress("OTA Update", tag.c_str(), "Downloading...", pct);
          lastPct = pct;
        }
      }
    } else if (!dlClient.connected()) {
      Serial.printf("[OTA] connection closed at %d/%d\n", written, contentLen);
      break;
    } else {
      if (millis() - lastData > 30000) {
        Serial.printf("[OTA] stalled at %d/%d\n", written, contentLen);
        break;
      }
      delay(1);  // yield proper RTOS tick to Core-0 WiFi stack
    }
  }

  dlClient.stop();
  Serial.printf("[OTA] written: %d / %d\n", written, contentLen);

  if (written == contentLen) {
    esp_err_t err = esp_ota_end(otaHandle);
    if (err == ESP_OK) err = esp_ota_set_boot_partition(part);
    if (err == ESP_OK) {
      displayManager.showOtaProgress("OTA Update", "", "Update OK", 100);
      otaRunning = false;
      delay(2000);
      ESP.restart();
    } else {
      Serial.printf("[OTA] finalize error: 0x%x\n", err);
    }
  }

  displayManager.showOtaProgress("OTA Update", "", "OTA failed");
  otaRunning = false;
  delay(3000);
}

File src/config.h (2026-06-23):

#ifndef CONFIG_H
#define CONFIG_H

#include <Arduino.h>
#include <Preferences.h>

#define FIRMWARE_VERSION "1.2.0"
#define OTA_REPO "VID-PRO/BambuTagger-AMS-C"

#define NUM_SLOTS 4

// --- Pin Assignments ---
// SPI Bus
#define SPI_MOSI 23
#define SPI_MISO 19
#define SPI_SCK  18

// RC522 CS (SS) pins
const uint8_t SS_PINS[NUM_SLOTS]  = {13, 12, 14, 27};
// RC522 RST pins
const uint8_t RST_PINS[NUM_SLOTS] = {26, 25, 33, 32};
// WS2812 LED daisy chain (single data pin, 4 LEDs in series)
#define LED_DATA_PIN   15
#define LED_COUNT      4
#define LED_BRIGHTNESS 32

// SPI TFT (240x240 1.3" ST7789VW)
#define TFT_BLK  2
#define TFT_DC   4
#define TFT_RES  5
#define TFT_CS   -1
#define TFT_SCL  16
#define TFT_SDA  17

// --- RFID Settings ---
#define RFID_POLL_INTERVAL_MS  100
#define RFID_DEBOUNCE_MS       500
#define NTAG_PAGE_SIZE         4
#define NTAG_USER_START_PAGE   4
#define NTAG_MAX_PAGES         231

// --- Spool Info Structure ---
struct SpoolInfo {
  bool present;
  char uid[16];
  char materialType[32];
  char detailedType[256];
  char color[16];
  char colorHex[9];
  uint16_t remainingGrams;
  uint16_t totalGrams;
  uint16_t nozzleTempMin;
  uint16_t nozzleTempMax;
  char batchNumber[32];
  char manufacturer[32];
  uint32_t lastSeen;
  bool tagReadSuccess;
};

// --- System Configuration ---
struct SystemConfig {
  char wifiSSID[32];
  char wifiPassword[64];
  char printerIP[16];
  uint16_t printerPort;
  char printerAccessCode[48];
  char printerSerial[32];
  char deviceName[32];
  uint8_t amsUnit;  // 0=A, 1=B, 2=C, 3=D
  bool mqttEnabled;
  bool mqttUseTLS;
  uint32_t mqttUpdateIntervalMs;
  char mqttTopicPrefix[64];
  bool layoutVertical;
};

// --- Default Configuration ---
inline SystemConfig getDefaultConfig() {
  SystemConfig cfg;
  strcpy(cfg.wifiSSID, "");
  strcpy(cfg.wifiPassword, "");
  strcpy(cfg.printerIP, "192.168.1.100");
  cfg.printerPort = 8883;
  strcpy(cfg.printerAccessCode, "");
  strcpy(cfg.printerSerial, "");
  strcpy(cfg.deviceName, "BambuTagger-AMS");
  cfg.amsUnit = 0;
  cfg.mqttEnabled = false;
  cfg.mqttUseTLS = false;
  cfg.mqttUpdateIntervalMs = 3000;
  strcpy(cfg.mqttTopicPrefix, "device");
  cfg.layoutVertical = false;
  return cfg;
}

// --- Persistent Config Helpers ---
inline void loadConfig(SystemConfig &cfg) {
  Preferences prefs;
  prefs.begin("bambu-ams", true);
  cfg = getDefaultConfig();
  if (prefs.isKey("wifiSSID")) prefs.getString("wifiSSID", cfg.wifiSSID, sizeof(cfg.wifiSSID));
  if (prefs.isKey("wifiPwd")) prefs.getString("wifiPwd", cfg.wifiPassword, sizeof(cfg.wifiPassword));
  if (prefs.isKey("printerIP")) prefs.getString("printerIP", cfg.printerIP, sizeof(cfg.printerIP));
  cfg.printerPort = prefs.getUShort("printerPort", cfg.printerPort);
  if (prefs.isKey("accCode")) prefs.getString("accCode", cfg.printerAccessCode, sizeof(cfg.printerAccessCode));
  if (prefs.isKey("printerSN")) prefs.getString("printerSN", cfg.printerSerial, sizeof(cfg.printerSerial));
  if (prefs.isKey("devName")) prefs.getString("devName", cfg.deviceName, sizeof(cfg.deviceName));
  cfg.mqttEnabled = prefs.getBool("mqttEn", cfg.mqttEnabled);
  cfg.mqttUseTLS = prefs.getBool("mqttTLS", cfg.mqttUseTLS);
  cfg.mqttUpdateIntervalMs = prefs.getULong("mqttInt", cfg.mqttUpdateIntervalMs);
  cfg.amsUnit = prefs.getUChar("amsUnit", cfg.amsUnit);
  cfg.layoutVertical = prefs.getBool("layoutVertical", false);  
  prefs.end();
}

inline void saveConfig(const SystemConfig &cfg) {
  Preferences prefs;
  prefs.begin("bambu-ams", false);
  prefs.putString("wifiSSID", cfg.wifiSSID);
  prefs.putString("wifiPwd", cfg.wifiPassword);
  prefs.putString("printerIP", cfg.printerIP);
  prefs.putUShort("printerPort", cfg.printerPort);
  prefs.putString("accCode", cfg.printerAccessCode);
  prefs.putString("printerSN", cfg.printerSerial);
  prefs.putString("devName", cfg.deviceName);
  prefs.putBool("mqttEn", cfg.mqttEnabled);
  prefs.putBool("mqttTLS", cfg.mqttUseTLS);
  prefs.putULong("mqttInt", cfg.mqttUpdateIntervalMs);
  prefs.putUChar("amsUnit", cfg.amsUnit);
  prefs.putBool("layoutVertical", cfg.layoutVertical);
  prefs.end();
}

#endif

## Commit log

2026-06-08 led brightness control
2026-06-09 fixed unstable ota update
    [BambuTagger-AMS-C.ino, config.h]
